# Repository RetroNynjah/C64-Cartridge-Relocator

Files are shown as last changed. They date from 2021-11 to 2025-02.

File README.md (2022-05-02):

# Retroninja C64 Cartridge Relocator
90 degree adapter for mounting a C64 cartridge vertically

The top/front side of the cartridge should be facing the computer.

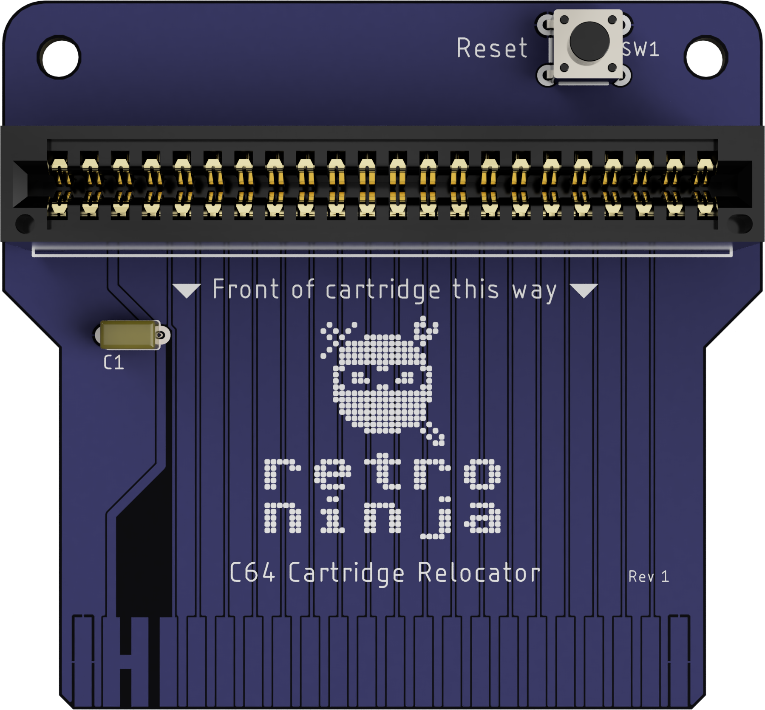
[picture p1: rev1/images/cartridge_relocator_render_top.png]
render


Edge connector that should fit: ‎395-044-520-201‎	https://www.digikey.se/product-detail/sv/395-044-520-201/151-1428-ND/559822?itemSeq=381630769

Capactitor is a 100nF ceramic cap with 5mm pitch. For good measure. Other values could work or even no capacitor at all.

Reset button is optional but a 6x6mm tactile switch is suitable and always nice to have.

fierodoug has designed a 3d-printable enclosure for this board. The design can be found on Thingiverse at https://www.thingiverse.com/thing:5159147

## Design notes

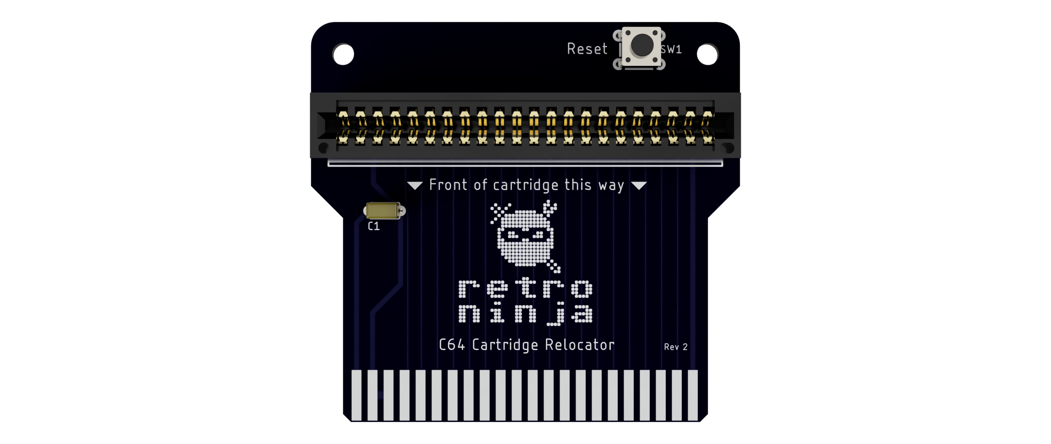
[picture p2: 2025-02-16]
rev2/images/cartridge_relocator_render_top.png

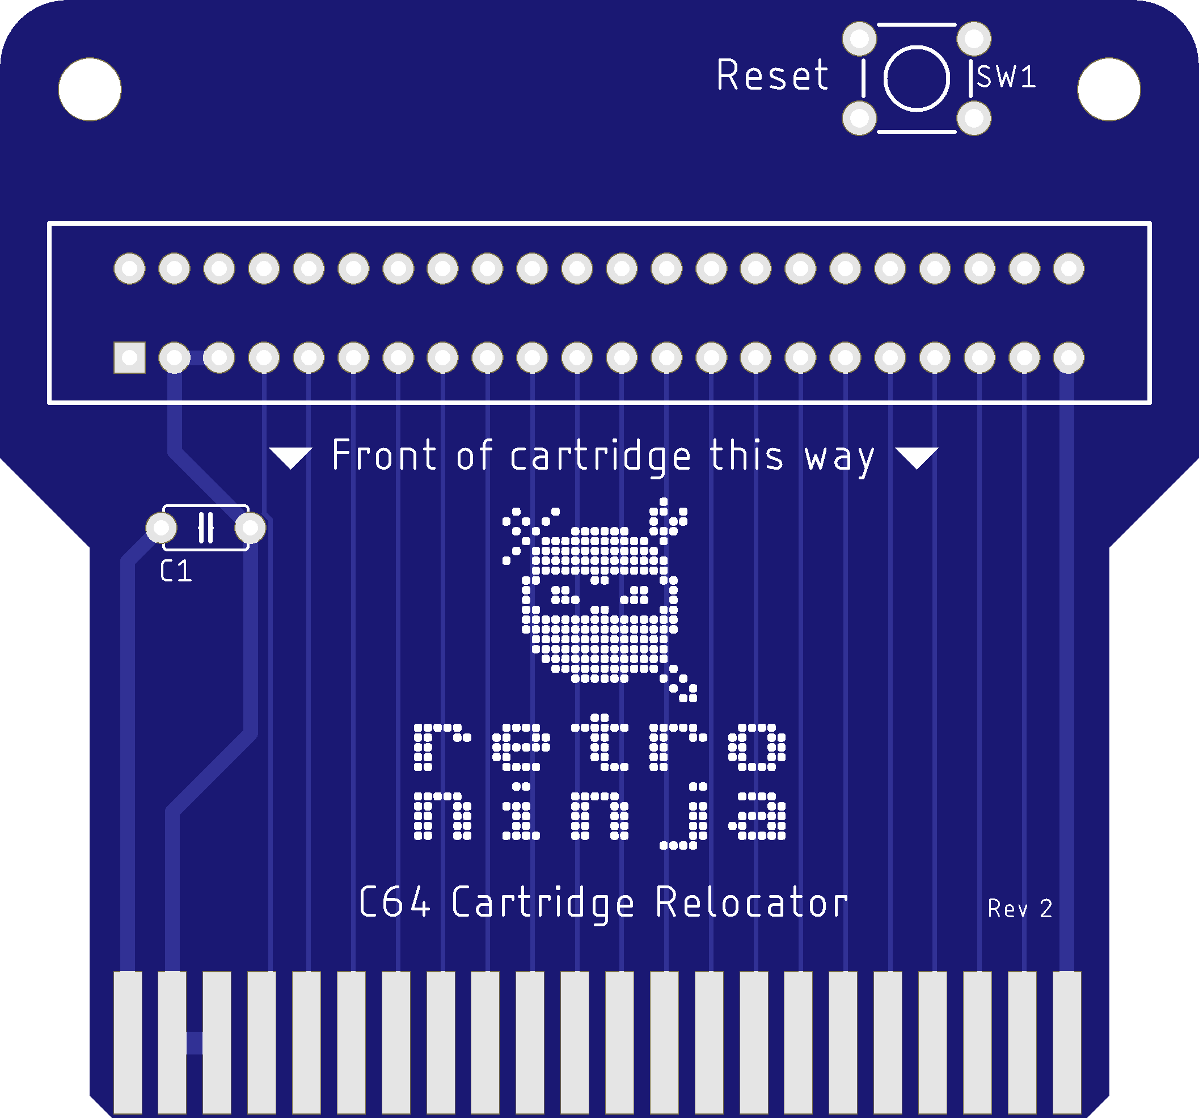
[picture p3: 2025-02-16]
rev2/images/cartridge_relocator_top.png

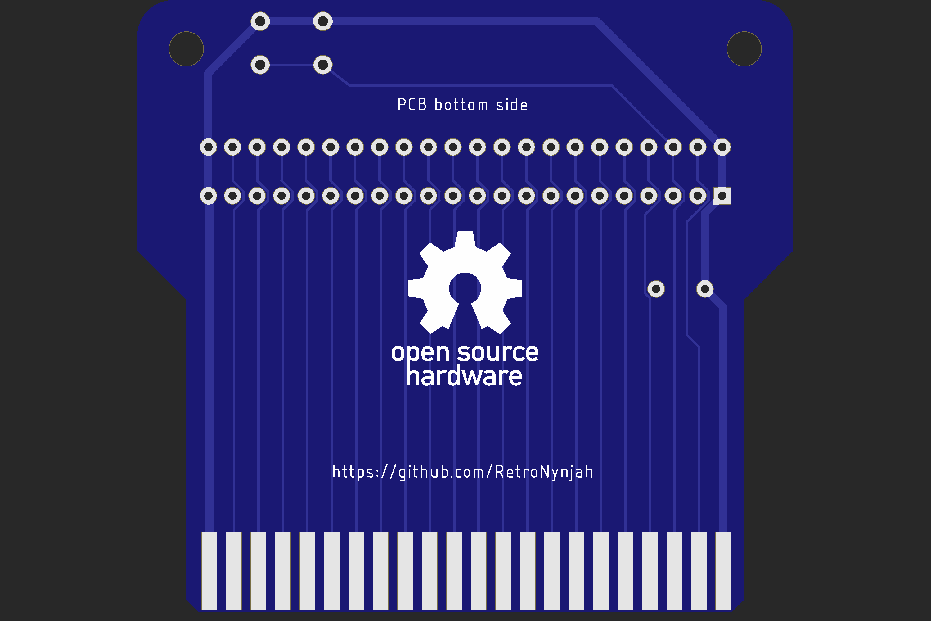
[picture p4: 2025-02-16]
rev2/images/cartridge_relocator_bottom.png

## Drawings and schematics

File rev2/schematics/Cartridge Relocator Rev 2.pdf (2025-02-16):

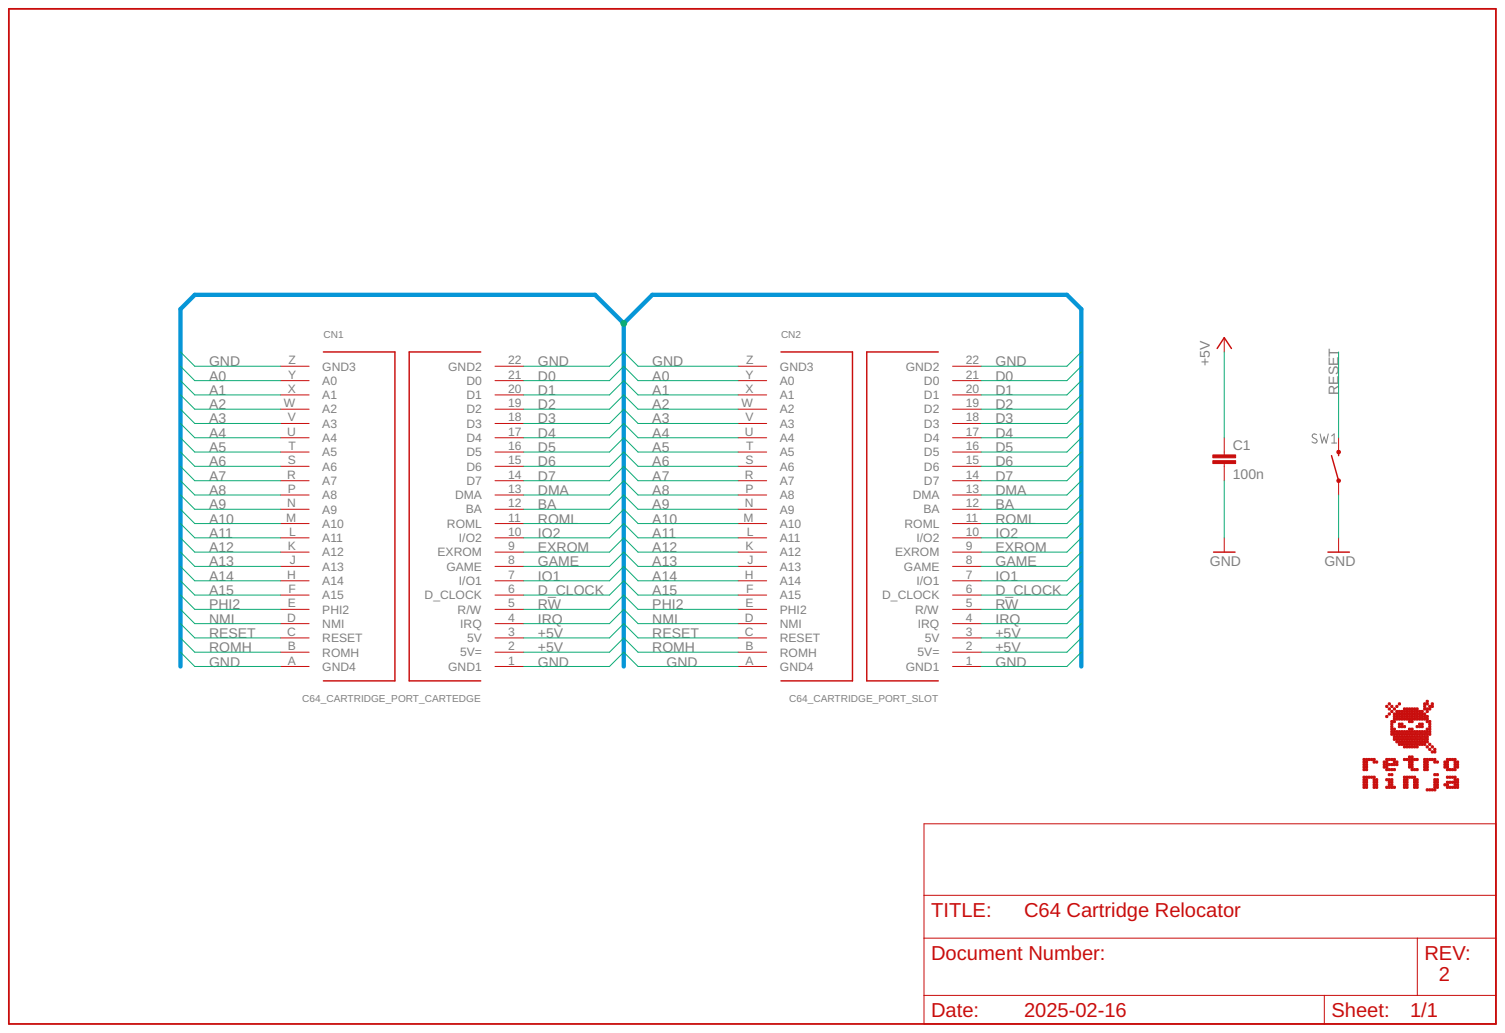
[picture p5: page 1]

Document Number: | REV: 2

Date: 2025-02-16 | Sheet: 1/1

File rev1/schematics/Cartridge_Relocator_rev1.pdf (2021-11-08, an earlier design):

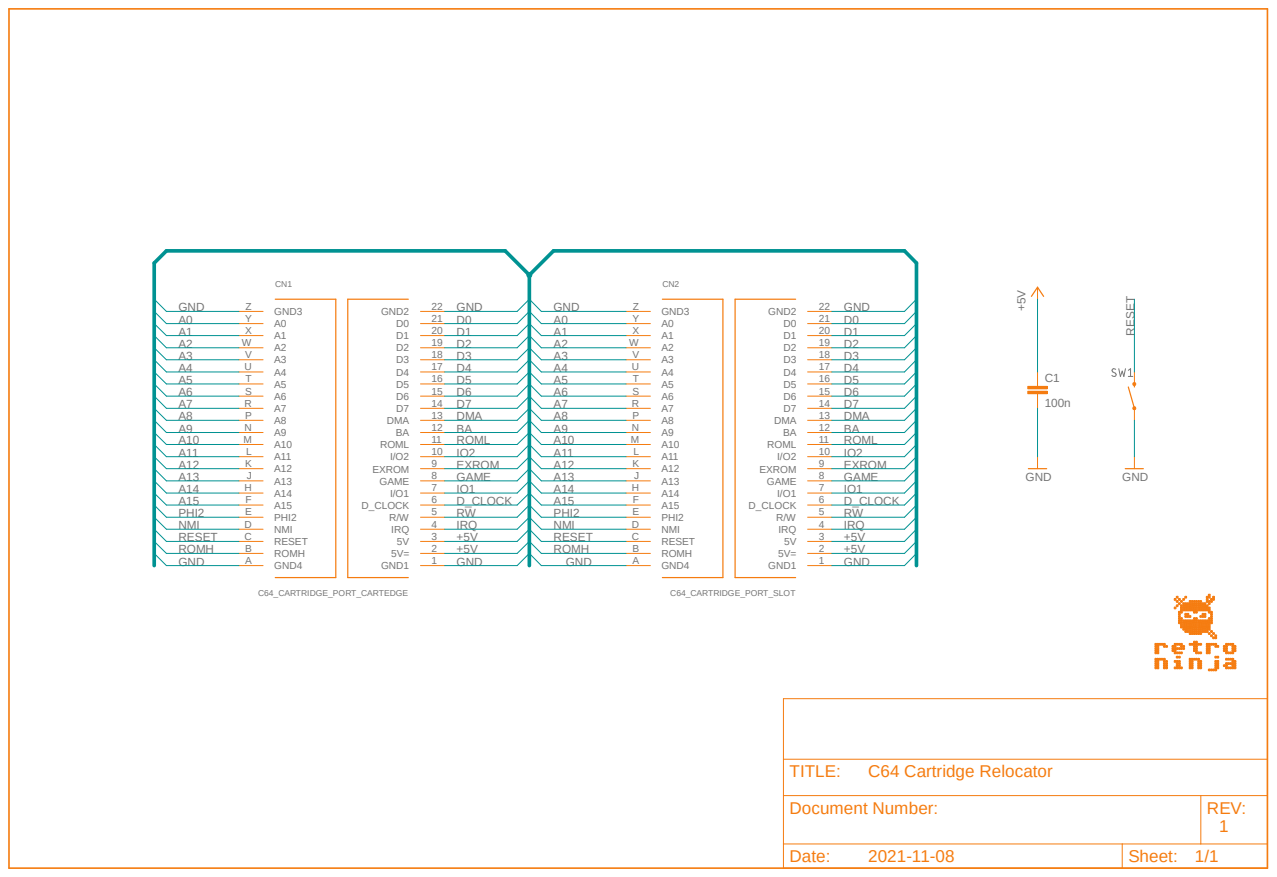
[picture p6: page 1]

Document Number: | REV: 1

Date: 2021-11-08 | Sheet: 1/1

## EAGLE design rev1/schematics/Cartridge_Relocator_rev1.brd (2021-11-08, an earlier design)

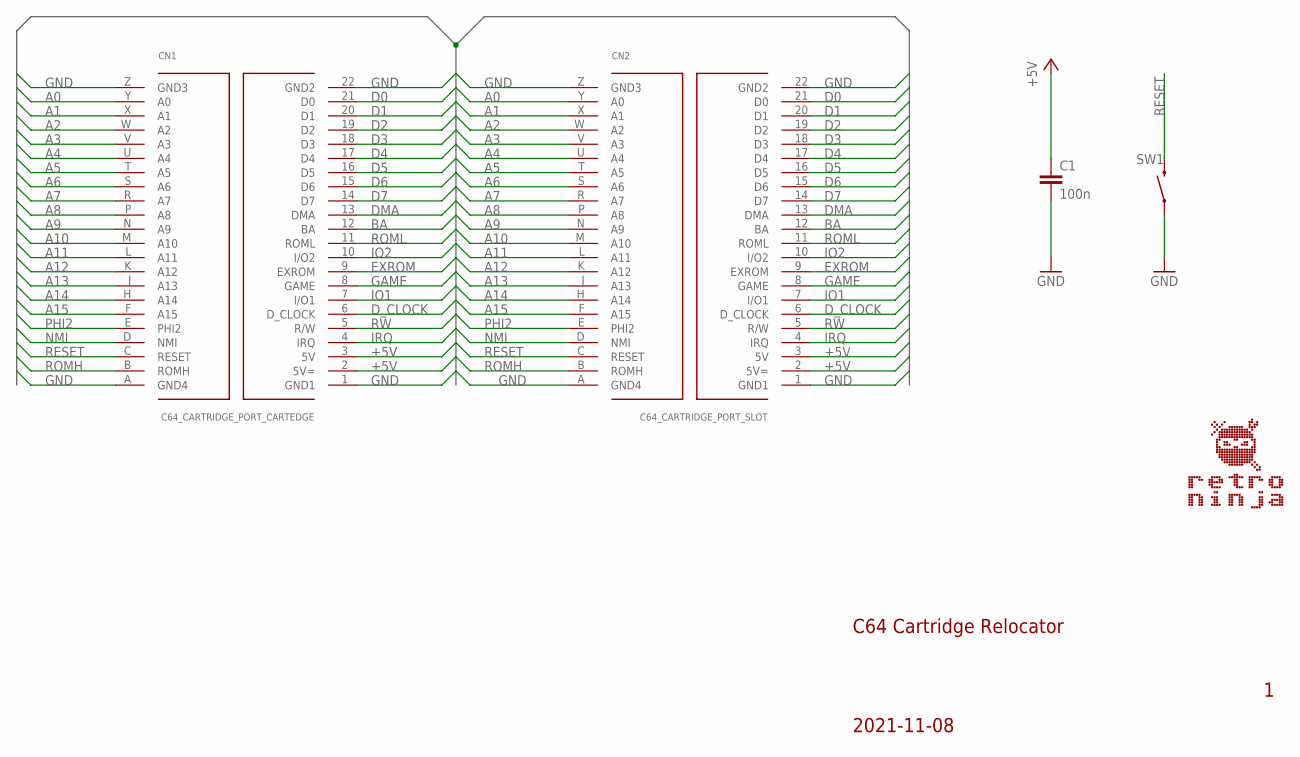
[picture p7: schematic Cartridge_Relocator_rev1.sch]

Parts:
C1: 100n; CAP_5MM_2.5X5.0_ROUND
CN1: C64_CARTRIDGE_PORT_CARTEDGE; C64_CARTRIDGE_BOARDEDGE
CN2: C64_CARTRIDGE_PORT_SLOT; C64_CARTRIDGE_SLOT
SW1: SWITCH_MOMENTARY; SWITCH_MOM_6.0MMX5.0MM

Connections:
+5V: C1.1, CN1.2 (5V=), CN1.3 (5V), CN2.2 (5V=), CN2.3 (5V)
A0: CN1.Y (A0), CN2.Y (A0)
A1: CN1.X (A1), CN2.X (A1)
A2: CN1.W (A2), CN2.W (A2)
A3: CN1.V (A3), CN2.V (A3)
A4: CN1.U (A4), CN2.U (A4)
A5: CN1.T (A5), CN2.T (A5)
A6: CN1.S (A6), CN2.S (A6)
A7: CN1.R (A7), CN2.R (A7)
A8: CN1.P (A8), CN2.P (A8)
A9: CN1.N (A9), CN2.N (A9)
A10: CN1.M (A10), CN2.M (A10)
A11: CN1.L (A11), CN2.L (A11)
A12: CN1.K (A12), CN2.K (A12)
A13: CN1.J (A13), CN2.J (A13)
A14: CN1.H (A14), CN2.H (A14)
A15: CN1.F (A15), CN2.F (A15)
BA: CN1.12 (BA), CN2.12 (BA)
D0: CN1.21 (D0), CN2.21 (D0)
D1: CN1.20 (D1), CN2.20 (D1)
D2: CN1.19 (D2), CN2.19 (D2)
D3: CN1.18 (D3), CN2.18 (D3)
D4: CN1.17 (D4), CN2.17 (D4)
D5: CN1.16 (D5), CN2.16 (D5)
D6: CN1.15 (D6), CN2.15 (D6)
D7: CN1.14 (D7), CN2.14 (D7)
DMA: CN1.13 (DMA), CN2.13 (DMA)
D_CLOCK: CN1.6 (D_CLOCK), CN2.6 (D_CLOCK)
EXROM: CN1.9 (EXROM), CN2.9 (EXROM)
GAME: CN1.8 (GAME), CN2.8 (GAME)
GND: C1.2, CN1.1 (GND1), CN1.22 (GND2), CN1.A (GND4), CN1.Z (GND3), CN2.1 (GND1), CN2.22 (GND2), CN2.A (GND4), CN2.Z (GND3), SW1.1, SW1.2 (1)
IO1: CN1.7 (I/O1), CN2.7 (I/O1)
IO2: CN1.10 (I/O2), CN2.10 (I/O2)
IRQ: CN1.4 (IRQ), CN2.4 (IRQ)
NMI: CN1.D (NMI), CN2.D (NMI)
PHI2: CN1.E (PHI2), CN2.E (PHI2)
RESET: CN1.C (RESET), CN2.C (RESET), SW1.3 (2), SW1.4 (2)
ROMH: CN1.B (ROMH), CN2.B (ROMH)
ROML: CN1.11 (ROML), CN2.11 (ROML)
RW: CN1.5 (R/W), CN2.5 (R/W)

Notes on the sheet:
2021-11-08
C64 Cartridge Relocator

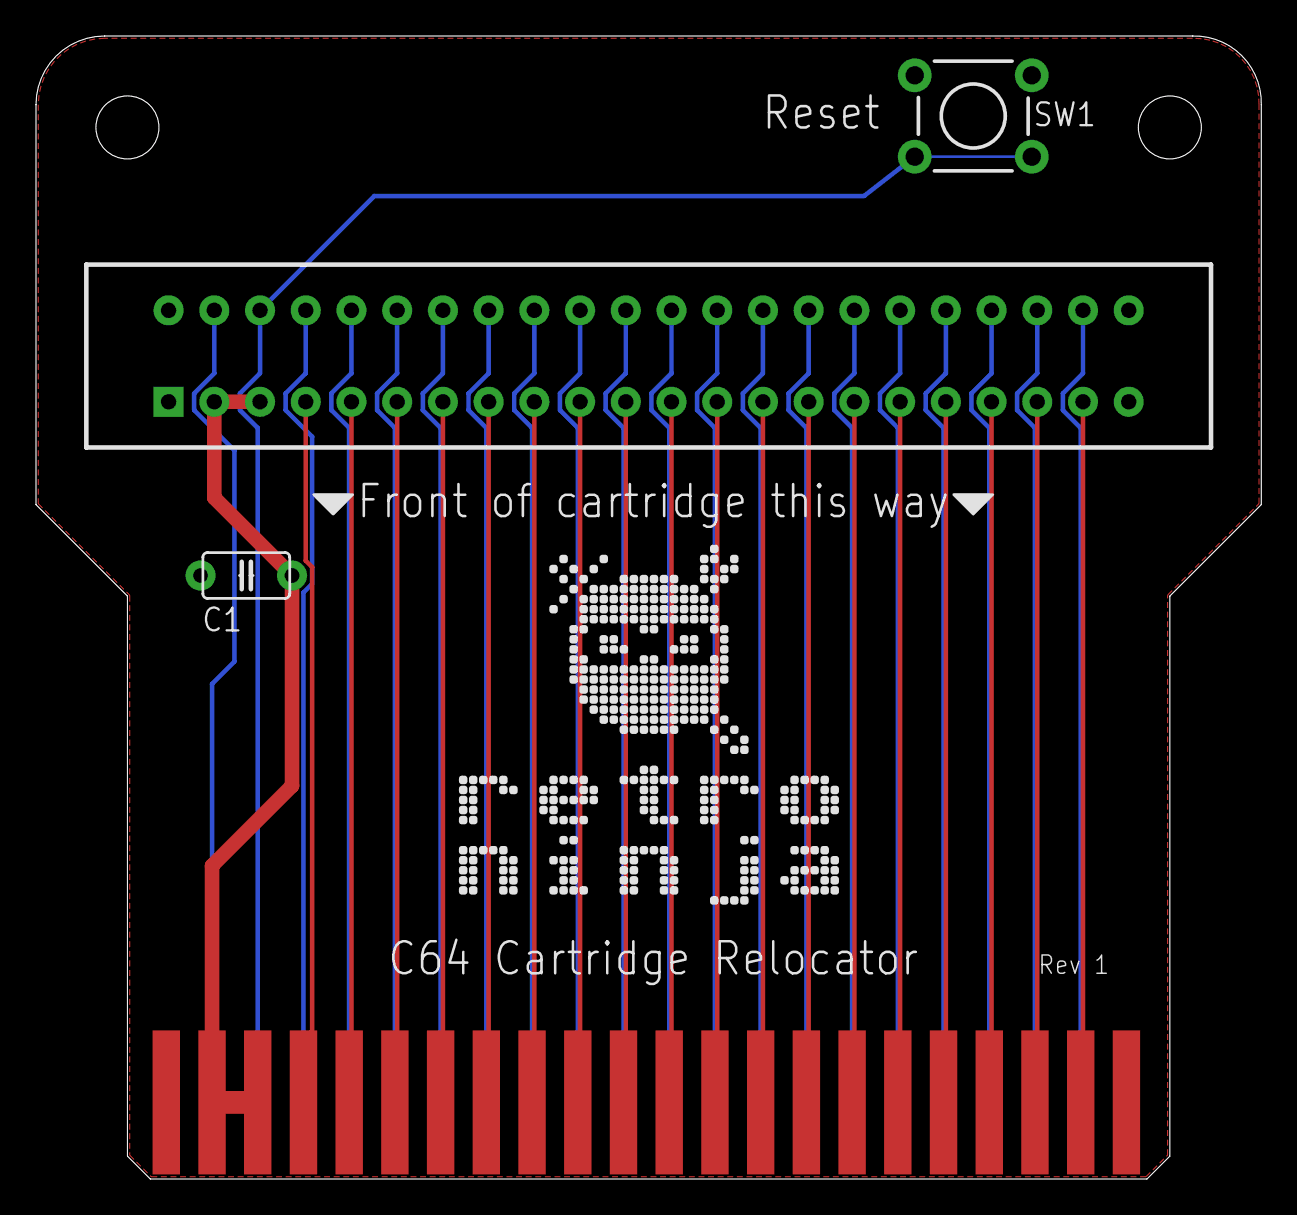
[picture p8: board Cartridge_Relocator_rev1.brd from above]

Board: 2 copper layers, 68.1 x 63.5 mm, 6 parts (1 on the bottom side), 40 nets.

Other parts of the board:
U$1: RETRONINJA_20MM
U$2: OSHW_16MM

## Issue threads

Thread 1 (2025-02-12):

GND plane should not extend between connector fingers

c1570, 2025-02-12:
The GND plane should not extend between expansion port connector fingers as that makes the design somewhat prone to short circuits. Exclude the port area from the GND plane.

RetroNynjah, 2025-02-16:
You are right. There shouldn't be any ground planes between the pins. In fact, this board doesn't even need ground planes so I have removed them.

Closed 2025-02-16.

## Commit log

2021-11-08 Minor update to board, images and gerbers
    [Cartridge_Relocator_rev1.brd]
2022-05-02 Link to enclosure
2025-02-16 Rev 2 PCB
    New revision of PCB without ground planes
